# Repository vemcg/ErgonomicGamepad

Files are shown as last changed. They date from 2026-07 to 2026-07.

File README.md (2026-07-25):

# ErgonomicGamepad

Custom ergonomic gaming keypad PCB project (KiCad) with a 4x6 key matrix, hot-swap sockets, and USB-C.

## Overview

This repo contains the schematic, PCB, and production support files for an ATmega32U4-based ergonomic keypad.

## Hardware Summary

| Item | Value |
|---|---|
| MCU | ATmega32U4 (TQFP-44) |
| Key Matrix | 4 rows x 6 columns (24 keys) |
| Switch Interface | MX-compatible Kailh hot-swap sockets |
| USB | USB-C receptacle |
| Clock | 16 MHz crystal |
| Passive Size | 0603 resistors/capacitors |
| Protection/Diodes | 1N4148 matrix diodes, 1N5819WS Schottky |

## Core Project Files

- `ErgonomicGamepad.kicad_sch` - Schematic
- `ErgonomicGamepad.kicad_pcb` - PCB layout
- `ErgonomicGamepad.kicad_pro` - KiCad project
- `jlcpcb/production_files/jlc_sourcing_bom_template.csv` - Main sourcing/BOM table
- `jlcpcb/production_files/verify_stock_before_ordering.csv` - Pre-order stock/sourcing risk checklist (MCU lead time, hand-sourced sockets/connectors/switches)
- `jlcpcb/gerber/` - Manufacturing output folder

## Pinout Baseline

### Matrix

| Signal | Pins |
|---|---|
| ROW1-ROW4 | PF7, PF6, PF5, PF4 |
| COL1-COL6 | PD1, PD2, PD3, PD4, PD5, PD6 |

### Programming Header (ISP)

| Signal | Pin Mapping |
|---|---|
| SCK | PB1 |
| MOSI | PB2 |
| MISO | PB3 |
| RESET | J5 pin 5 -> U1 ~RESET |

## USB-C Implementation (Resolved)

J1 is an HRO `TYPE-C-31-M-12` receptacle - hybrid retention (SMT signal/power
pins plus through-hole shell tabs) for stronger cable-insertion durability
than an SMT-only part. This is a USB 2.0 device-only implementation (power +
D+/D-); no SuperSpeed/Alt-Mode pins are used.

- **Orientation**: fully reversible. Both D+ pads (A6 and B6) are tied
  together at the connector, and both D- pads (A7 and B7) are tied together,
  so the plug works in either orientation.
- **Signal path**: connector D+/D- -> U2 (`USBLC6-2SC6` ESD protection array)
  -> series resistors R1/R2 (20R) -> U1 D-/D+ pins, with TP3/TP4 tapping the
  MCU-side D-/D+ nets for debug access.
- **CC (device-mode/UFP)**: CC1 and CC2 each pull down to GND through a 5.1k
  resistor (R4, R5) - the standard passive UFP presentation, no CC logic IC.
- **Shield/GND**: J1's shield pin (`SH`) ties directly to GND (no RC/ferrite
  isolation).
- **Power path**: VBUS feeds +5V through D1 (`1N5819WS` Schottky) gated by
  JP1 (power-path select jumper - see Jumper Shunts below); J7 (external
  2-pin power connector) feeds +5V directly. The Schottky prevents VBUS from
  being back-fed if J7 external power is connected while a USB cable is also
  plugged in.

## Debug / Test Points

- **TP1-TP7**: internal signal debug points (power-select node, GND
  reference, USB D+/D-, crystal XTAL1/XTAL2, USB regulator cap node) using
  the small `TestPoint_Pad_D1.5mm` footprint - sized for a fine meter probe
  or hook, not a full-size clip.
- **TP8 (+5V) / TP9 (GND)**: dedicated power-rail clip points, intended to
  be placed at the board edge for easy alligator-clip access during bring-up
  and testing. These use the larger `TestPoint_THTPad_D3.0mm_Drill1.5mm`
  footprint (a real drilled through-hole pad, not just a flat SMD pad) so an
  actual clip has something to bite onto. Kept separate from TP2 (which
  stays with the internal signal-debug cluster near the MCU) since GND is a
  single net and a second access point elsewhere costs nothing electrically.

## Footprint Baseline (Current)

- SW1-SW24: `Switch_Keyboard_Hotswap_Kailh:SW_Hotswap_Kailh_MX_Plated_1.00u`
- J1: `Connector_USB:USB_C_Receptacle_HRO_TYPE-C-31-M-12`
- R1-R7: `Resistor_SMD:R_0603_1608Metric`
- C1-C5: `Capacitor_SMD:C_0603_1608Metric`
- D25-D26: `LED_SMD:LED_0603_1608Metric`
- TP1-TP7: `TestPoint:TestPoint_Pad_D1.5mm`
- TP8/TP9: `TestPoint:TestPoint_THTPad_D3.0mm_Drill1.5mm` (edge-mounted power/ground clip points - see Debug / Test Points above)
- J2/J3/J4/J6: `Connector_JST:JST_XH_B5B-XH-A_1x05_P2.50mm_Vertical` (DNP - see Satellite Board Cables below)
- J7: `PinHeader_1x02_P2.54mm_Vertical`
- J5: `PinHeader_2x03_P2.54mm_Vertical`
- JP1/JP2: `Connector_PinHeader_2.54mm:PinHeader_1x02_P2.54mm_Vertical`
- Y1: `Crystal:Crystal_SMD_3215-2Pin_3.2x1.5mm`
- SWR1: `Button_Switch_SMD:SW_SPST_B3U-3000P`

## Jumper Shunts Needed (Not Part of PCBA)

JP1 (power-path select) and JP2 (forces hardware bootloader via U1 pin 33 /
HWB when bridged) are populated as bare 2-pin headers during JLCPCB assembly,
but the assembly process does not install a shunt on them - a jumper shunt is
a friction-fit plastic/metal cap, not a soldered part, so it has to be
installed by hand after the boards arrive.

Buy separately (not on the PCBA BOM):
- **2.54mm 2-pin jumper shunt cap** - e.g. BOOMELE, LCSC `C5305` (~$0.01/unit,
  50-piece minimum order on LCSC). Any standard 2.54mm/0.1" shunt works; this
  is a common commodity part also sold on Amazon/DigiKey/etc.
- Need at least 2 (one per jumper), but buy a small handful (the LCSC MOQ is
  50 anyway) since they're easy to lose.

## Switches & Keycaps Needed (Not Part of PCBA)

SW01-SW24 are Kailh MX hotswap sockets, soldered directly to the board (see
Footprint Baseline above), but the actual keyswitches and keycaps are
separate hand-sourced items that get plugged in after assembly - the whole
point of a hotswap board is that these aren't soldered.

- **Hotswap sockets** (on-board, hand-soldered): Kailh `CPG151101S11-16`,
  LCSC `C5156480` - https://www.lcsc.com/datasheet/C5156480.pdf. Currently
  shows near-zero LCSC stock (consignment-style listing), so plan to
  hand-source and hand-solder these rather than rely on JLCPCB
  auto-placement - see Progress notes below. Need 24 plus a few spares.
  Each socket takes 2 solder joints (through-hole); the extra alignment
  pins in the footprint hold it steady while soldering. For practical
  hobbyist purchasing, the real path is AliExpress - there are multiple
  listings selling genuine Kailh hotswap sockets in small hobbyist-friendly
  quantities (30/90/110-packs), which is how most individual keyboard
  builders actually buy these - or a specialty keyboard-parts retailer
  like splitkb.com, which stocks Kailh hotswap sockets specifically for
  this use case.
- **Keyswitches** (plug into the sockets, not soldered): Cherry MX Brown
  (tactile), official part `MX1A-G1NW`. Also frequently out of stock on
  LCSC - source from a specialty mechanical-keyboard parts retailer instead
  (e.g. KBDfans, NovelKeys, Mechanicalkeyboards.com, or similar). Since the
  socket is switch-agnostic (any standard MX-footprint switch fits), a
  well-regarded MX-compatible clone switch would also work if genuine
  Cherry isn't available. Need 24 plus a few spares.
- **Keycaps**: MX-compatible (cross-stem) keycaps, not yet specced -
  profile (OEM/Cherry/DSA/etc.), material, and colorway are a personal
  choice. Note this layout is a non-standard ergonomic 4x6 matrix, not a
  regular keyboard row layout, so a generic pre-made keycap set is unlikely
  to have correctly-sculpted keycaps for every position - uniform-profile
  (same shape regardless of position) or blank keycaps are the simplest
  option unless a custom set is planned.

## Satellite Board Cables Needed (Not Part of PCBA)

J2/J3/J4/J6 connect the two satellite switch boards to the main board (ROW1-4
+ COL1 per connector - no power needed, see Pinout Baseline). They're marked
DNP on the JLCPCB assembly BOM since through-hole headers get hand-soldered
after the boards arrive, same reasoning as the hotswap sockets above.

- **Male headers** (on-board, hand-soldered): JST-XH 5-pin, `B5B-XH-A`
  (matches the footprint above). Genuine JST stock from **Digi-Key** or
  **Mouser** (search `B5B-XH-A` directly), or cheaper from **LCSC/JLCPCB**
  (search "XH 5P" or the part number `B5B-XH-A(LF)(SN)`) - the latter is also
  orderable through JLCPCB assembly if DNP is ever lifted. Generic
  multi-packs from Amazon/AliExpress work fine too for prototyping. Need 4
  (one per connector) plus spares.
- **Female-to-female cables**: JST-XH 5-pin, both ends female, connecting
  each main-board header to its matching satellite-board header. Target
  length ~3-4in. Best sourced from **AliExpress** (search "JST XH 2.54 5 pin
  cable" - widely available in 10/15/20/30cm, some sellers offer custom
  lengths) or **Amazon** (search "JST XH 5 pin cable" - mostly RC/battery
  sellers, lengths cluster around 15-30cm with some 10cm/~4in options). If
  the exact length/pinout combo isn't available premade, a JST-XH crimp tool
  (~$15-20) plus loose housings/terminals (pennies each, same vendors) makes
  it easy to build the 2 needed cables to spec. Individual wires are
  flexible (stranded, not ribbon) so routing/twisting around the enclosure
  isn't a concern.

## Progress (Brief)

Done:
- Schematic is component-complete.
- Footprints assigned for all currently tracked parts.
- Schematic and PCB baseline are synced.
- ISP signal mapping corrected and documented.
- JLC sourcing workflow files are in place.
- USB-C orientation, CC, ESD, shield, and power-path decisions locked and documented.

Not done yet:
- Component placement refinement.
- PCB routing completion.
- Panelization/mechanical finalization.
- Final DRC-clean release candidate.
- Gerber/BOM/CPL release package for fabrication.
- Firmware development.

## Process Checklist

For the full detailed build, verification, and manufacturing checklist, use [PROCESS.md](PROCESS.md).

---

Last Updated: July 2026
Project Status: Pre-Layout Baseline

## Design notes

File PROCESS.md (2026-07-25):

# ErgonomicGamepad Process Checklist (Detailed)

Use this file as the full grind checklist from project prep through fabrication handoff.

## How To Use This Checklist

1. Work from top to bottom.
2. Check items as you complete them.
3. If blocked, add a short note under the blocked item and continue with the next independent item.
4. Commit often.

## 0) Project Setup (One-Time)

- [X] Install KiCad 10.0+.
- [X] Open `ErgonomicGamepad.kicad_pro`.
- [X] Confirm project opens cleanly (no stale lock-file confusion from old sessions).
- [X] Confirm local libraries needed by footprints are available.
- [X] Create a baseline git commit before making major changes.

Verification:
- [X] Open schematic and PCB once each and confirm they load without missing file errors.

## 1) Requirements Freeze (Before Heavy Layout)

- [X] Confirm matrix goal: 4x6 (24 keys).
- [X] Confirm switch/socket strategy (hot-swap MX).
- [X] Confirm USB-C connector part and orientation strategy.
- [X] Confirm power path strategy and required protection parts.
- [ ] Confirm mounting-hole plan and any enclosure constraints.
- [X] Confirm debug/programming connector strategy (ISP).

USB-C connector part + orientation strategy details:
- [X] Pick the exact connector MPN first (mid-mount vs top-mount, horizontal vs vertical, SMT-only vs hybrid with through-hole shell tabs).
- [X] Confirm your use case is USB 2.0 device-only (power + D+/D-), not full USB-C feature set.
- [X] Decide plug orientation behavior:
- [X] Fully reversible: tie A6 to B6 for D+, and A7 to B7 for D- at the connector footprint.
- [X] Confirm CC implementation for device mode (UFP): place 5.1k pull-down resistors from CC1 and CC2 to GND.
- [X] Verify shield/shell connection plan (direct GND or GND through RC/ferrite policy per your EMI goal) and keep it consistent with board grounding strategy.
- [ ] Confirm mechanical robustness: shell-anchor pad dimensions, courtyard/keepout, and cable insertion stress path.
- [ ] Confirm footprint pin numbering and front/back orientation against the datasheet drawing before routing.
- [ ] Confirm nearby ESD protection placement for D+/D- and VBUS (close to connector, short return path to GND).

Verification for USB-C decision:
- [ ] Schematic symbol pins and footprint pins are cross-checked against connector datasheet pin map.
- [X] Chosen orientation strategy is documented in README so future revisions do not accidentally change behavior.

Recommended default for this project (unless a later constraint overrides it):
- [X] Use a USB-C receptacle with hybrid retention (SMT pins + through-hole shell tabs) for stronger cable-insertion durability.
- [X] Implement fully reversible USB 2.0 routing at the connector (A6/B6 joined for D+, A7/B7 joined for D-).
- [X] Use UFP CC pulldowns: 5.1k from CC1 to GND and 5.1k from CC2 to GND.
- [X] Add USB ESD protection array near connector for D+, D-, and VBUS.
- [X] Tie shield/shell to GND through your chosen policy and keep that policy documented consistently in schematic notes.

Final USB-C signoff checklist (release gate):
- [ ] Hard-edge decision locked: USB-C connector (J1) and side reset switch (SWR1) are both placed on north board edge.
- [ ] Panelization decision locked: avoid mouse-bites/V-score stress features near J1 shell tabs and SWR1 body keepout.
- [ ] J1 footprint and connector mechanical drawing are cross-checked (plug overhang, shell tab footprint, insertion clearance).
- [ ] USB 2.0 reversibility confirmed electrically: A6/B6 tied to D+, A7/B7 tied to D-.
- [ ] CC policy confirmed electrically: CC1 -> 5.1k -> GND and CC2 -> 5.1k -> GND.
- [ ] USB data path conditioning confirmed: series resistors on D+ and D- are placed and value-checked.
- [ ] USB ESD array part is added in schematic with explicit MPN/LCSC fields.
- [ ] USB ESD array footprint is placed close to J1 with short traces and short GND return.
- [ ] Shield/shell grounding policy is explicitly selected (direct GND or RC/ferrite policy) and implemented consistently.
- [ ] DRC/ERC re-run after USB/ESD updates with no unresolved manufacturing-blocking issues.

Verification:
- [ ] All above decisions are written in project notes/README.

## 2) Part Selection and Sourcing

- [X] Choose MPN for each symbol.
- [X] Prefer JLC/LCSC in-stock parts for assembled items.
- [X] Fill LCSC + MPN + Manufacturer in `jlcpcb/production_files/jlc_sourcing_bom_template.csv`.
- [X] Track pre-order stock/sourcing risk in `jlcpcb/production_files/verify_stock_before_ordering.csv`.
- [X] Mark DNP and hand-assembly items explicitly.

Verification:
- [X] No critical schematic component is missing a sourcing plan.
- [X] Every JLC-assembled line has a valid LCSC number or documented alternate.

## 3) Footprints and Mechanical Validity

- [ ] Assign footprint for every symbol.
- [ ] Cross-check each footprint against package dimensions in datasheet.
- [ ] Validate orientation for polarity/pin-1 sensitive parts.
- [ ] Confirm switch pitch/spacing and keycap clearance assumptions.
- [ ] Add/confirm mounting holes and keepouts.
- [ ] Add test points for key debug rails if needed.

Verification:
- [ ] No symbol left without footprint.
- [ ] Orientation-sensitive components are visually verified.

## 4) Schematic Electrical Verification (ERC)

- [ ] Run ERC (`Inspect -> Electrical Rules Checker`).
- [ ] Fix all blocking ERC errors.
- [ ] Document intentional warnings so future checks are clear.
- [ ] Review critical nets manually:
- [ ] MCU power and decoupling topology.
- [ ] USB D+ and D- connectivity.
- [ ] Reset and ISP lines.
- [ ] Matrix row/column mapping.

Verification:
- [ ] ERC is clean of blocking issues.
- [ ] Critical net review is complete and documented.

## 5) Schematic -> PCB Sync

- [ ] Run `Tools -> Update PCB from Schematic`.
- [ ] Confirm no missing-footprint errors.
- [ ] Confirm no accidental footprint remaps.
- [ ] Confirm netlist-level changes are expected.

Verification:
- [ ] PCB reflects current schematic exactly.

## 6) PCB Rule Setup Before Placement

- [ ] Define board outline on `Edge.Cuts`.
- [ ] Set clearance/track/via rules to fab-capable values.
- [ ] Define net classes (power, USB, matrix, etc.).
- [ ] Confirm layer stack/thickness target for fabrication.

Verification:
- [ ] Rules are set before routing starts.

## 7) Component Placement

- [ ] Place switch sockets first (mechanical anchor).
- [ ] Place MCU for practical fanout.
- [ ] Place decoupling caps close to MCU power pins.
- [ ] Place USB-C and nearby support/protection parts tightly.
- [ ] Place headers/test points for easy probe/cable access.
- [ ] Confirm mounting/tool clearance.

Verification:
- [ ] Components are placeable/routable without obvious congestion traps.

## 8) Routing

- [ ] Route power rails first.
- [ ] Route USB differential pair with clean geometry and consistent behavior.
- [ ] Route matrix traces with minimal crossover complexity.
- [ ] Add copper zones and refill.
- [ ] Remove weak geometry (needless neck-downs, awkward acute corners).

Verification:
- [ ] No critical net left in ambiguous state.

## 9) PCB Verification (DRC + Visual)

- [ ] Run DRC (`Inspect -> Design Rules Checker`).
- [ ] Fix all fabrication-blocking DRC issues.
- [ ] Confirm unrouted nets are zero before release (unless intentionally documented).
- [ ] Use 3D view for connector/mechanical collision sanity check.
- [ ] Re-run DRC after each major fix set.

Verification:
- [ ] DRC is clean for manufacturing intent.

## 10) Pre-Release Manufacturing Sanity

- [ ] Silkscreen labels are readable and off exposed pads.
- [ ] Polarized component markings are clear.
- [ ] Reference designators are present for assembly/debug.
- [ ] Fiducials/tooling are present if assembly process needs them.
- [ ] Freeze release commit and tag it.

Verification:
- [ ] Board is reviewable by someone else without guesswork.

## 11) Export Gerbers + Drills

In KiCad PCB Editor:

1. `File -> Plot...`
2. Select output format: `Gerber`
3. Plot required layers:
- [ ] F.Cu
- [ ] B.Cu
- [ ] F.SilkS
- [ ] B.SilkS
- [ ] F.Mask
- [ ] B.Mask
- [ ] Edge.Cuts
4. Click `Plot`.
5. Click `Generate Drill Files...`.
6. Generate Excellon drill files (PTH + NPTH as appropriate).
7. Package Gerbers + drills in one zip file.

Verification:
- [ ] Gerber set includes board outline and both mask layers.
- [ ] Drill files are present and non-empty.

## 12) Export Assembly Files (If JLC Assembly)

- [ ] Export BOM CSV.
- [ ] Export CPL/Pick-and-Place file.
- [ ] Ensure BOM refdes matches CPL refdes exactly.
- [ ] Ensure LCSC numbers are present where JLC places parts.
- [ ] Confirm DNP lines are clearly marked.

Verification:
- [ ] BOM/CPL pair imports without obvious mapping issues.

## 13) Upload and Manufacturer Review

- [ ] Upload Gerber zip to JLCPCB.
- [ ] Confirm board preview, dimensions, layer count, drill interpretation.
- [ ] Upload BOM + CPL if ordering assembly.
- [ ] Resolve rotation, offset, and refdes mapping issues.
- [ ] Review substitutions, price, and lead time.

Verification:
- [ ] Quote is valid and manufacturable with acceptable substitutions.

## 14) Final Release Lock

- [ ] Run ERC and DRC one final time on release revision.
- [ ] Confirm no accidental post-check edits.
- [ ] Save final manufacturing outputs under `jlcpcb/gerber/`.
- [ ] Tag release (example: `v0.1-proto1`).

Verification:
- [ ] Repo, outputs, and tag all match the same final revision.

## Daily Progress Loop (When You Feel Stuck)

1. Pick exactly one section above.
2. Complete 1 to 3 checkboxes only.
3. Run the relevant verification items.
4. Commit with a clear message.
5. Stop and continue tomorrow from the next unchecked item.

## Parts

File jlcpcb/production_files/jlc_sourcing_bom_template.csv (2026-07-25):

Quantity | Value | Footprint | References | LCSC | MPN | Manufacturer | Assembly | Notes
1 | ATmega32U4-A | Package_QFP:TQFP-44_10x10mm_P0.8mm | U1 | C44854 | ATMEGA32U4-AU | Microchip | JLC_SMT | Critical long-lead item; confirm live stock before finalizing order
1 | USBLC6-2SC6 | Package_TO_SOT_SMD:SOT-23-6 | U2 | C7519 | USBLC6-2SC6 | STMicroelectronics | JLC_SMT
1 | Crystal | Crystal:Crystal_SMD_3215-2Pin_3.2x1.5mm | Y1 | C13738 | X322516MLB4SI | YXC Crystal Oscillators | JLC_SMT
1 | USB_C_Receptacle_USB2.0_16P | Connector_USB:USB_C_Receptacle_HRO_TYPE-C-31-M-12 | J1 | C165948 | TYPE-C-31-M-12 | Korean Hroparts Elec | JLC_SMT
1 | AVR-ISP-6 | Connector_PinHeader_2.54mm:PinHeader_2x03_P2.54mm_Vertical_SMD | J5 | C32713283 | HX PZ2.54-2x3P TP | hanxia | JLC_SMT
1 | 1824417 | Connector_Phoenix_MC_HighVoltage:PhoenixContact_MCV_1,5_2-G-5.08_1x02_P5.08mm_Vertical | J7 | C5873683 | 1824417 | Phoenix Contact | JLC_SMT
2 | Jumper_2_Open | Connector_PinHeader_2.54mm:PinHeader_1x02_P2.54mm_Vertical | JP1,JP2 | C124375 | B-2100S02P-A110 | Ckmtw | JLC_SMT | Bare header only; JLCPCB does not install a shunt cap - buy separately and hand-install (see README Jumper Shunts section)
1 | 1N5819WS | Diode_SMD:D_SOD-323 | D1 | C191023 | 1N5819WS | Guangdong Hottech | JLC_SMT
24 | 1N4148WS | Diode_SMD:D_SOD-323 | DM01,DM02,DM03,DM04,DM05,DM06,DM07,DM08,DM09,DM10,DM11,DM12,DM13,DM14,DM15,DM16,DM17,DM18,DM19,DM20,DM21,DM22,DM23,DM24 | C917117 | 1N4148WS | JSMSEMI | JLC_SMT
1 | LED Pwr | LED_SMD:LED_0603_1608Metric | LED1 | C19273151 | YLED0603G | YONGYUTAI | JLC_SMT
1 | LED Dbg | LED_SMD:LED_0603_1608Metric | LED2 | C2286 | KT-0603R | Hubei KENTO Elec | JLC_SMT
2 | 22pF | Capacitor_SMD:C_0603_1608Metric | C1,C2 | C519390 | CC0603JRNPO8BN220 | YAGEO | JLC_SMT
1 | 1uF | Capacitor_SMD:C_0603_1608Metric | C3 | C106215 | CC0603KRX5R7BB105 | YAGEO | JLC_SMT
1 | 4.7uF | Capacitor_SMD:C_0603_1608Metric | C4 | C109456 | CC0603KRX5R6BB475 | YAGEO | JLC_SMT
1 | 100nF | Capacitor_SMD:C_0603_1608Metric | C5 | C14663 | CC0603KRX7R9BB104 | YAGEO | JLC_SMT
2 | 20R | Resistor_SMD:R_0603_1608Metric | R1,R2 | C125758 | RC0603FR-0720RL | YAGEO | JLC_SMT
1 | 10K | Resistor_SMD:R_0603_1608Metric | R3 | C98220 | RC0603FR-0710KL | YAGEO | JLC_SMT
2 | 5.1k | Resistor_SMD:R_0603_1608Metric | R4,R5 | C105580 | RC0603FR-075K1L | YAGEO | JLC_SMT
1 | 1k | Resistor_SMD:R_0603_1608Metric | R6 | C22548 | RC0603FR-071KL | YAGEO | JLC_SMT
1 | 330 | Resistor_SMD:R_0603_1608Metric | R7 | C105881 | RC0603FR-07330RL | YAGEO | JLC_SMT
1 | 10k | Resistor_SMD:R_0603_1608Metric | R8 | C98220 | RC0603FR-0710KL | YAGEO | JLC_SMT
1 | B3U-3000P | Button_Switch_SMD:SW_SPST_B3U-3000P | SWR1 | C963349 | B3U-3000P | Omron | JLC_SMT
24 | SW_DIP_x01 | Switch_Keyboard_Hotswap_Kailh:SW_Hotswap_Kailh_MX_Plated_1.00u | SW01,SW02,SW03,SW04,SW05,SW06,SW07,SW08,SW09,SW10,SW11,SW12,SW13,SW14,SW15,SW16,SW17,SW18,SW19,SW20,SW21,SW22,SW23,SW24 | C5156480 | CPG151101S11-16 | Kailh | DNP_HAND_SOLDER | LCSC listing is near-zero/consignment stock - hand-source from AliExpress or splitkb.com and hand-solder after assembly (see README Switches & Keycaps Needed); need 24 plus spares
4 | Conn_01x05 | Connector_JST:JST_XH_B5B-XH-A_1x05_P2.50mm_Vertical | J2,J3,J4,J6 | C157991 | B5B-XH-A(LF)(SN) | JST | DNP_HAND_SOLDER | Hand-solder after boards arrive; order male headers from Digi-Key/Mouser/LCSC and matching female-to-female JST-XH cables separately (see README Satellite Board Cables Needed); need 4 plus spares
7 | TestPoint | TestPoint:TestPoint_Pad_D1.5mm | TP1,TP2,TP3,TP4,TP5,TP6,TP7 |  |  |  | BARE_PCB | No placed component; in_bom=no, excluded from assembly BOM by design

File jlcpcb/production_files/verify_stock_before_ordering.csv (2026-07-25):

Item | References | Qty Needed | Channel | LCSC / MPN | Risk / Note
ATmega32U4-AU MCU | U1 | 1 | JLC assembly | C44854 / ATMEGA32U4-AU | Critical long-lead item - confirm live LCSC stock immediately before submitting the JLC order
Kailh hotswap sockets | SW01-SW24 | 24 + spares | Hand-source (AliExpress or splitkb.com) | C5156480 / CPG151101S11-16 | LCSC listing is near-zero/consignment stock - do not rely on JLC auto-placement; buy from a hobbyist-quantity AliExpress listing or splitkb.com instead
JST-XH 5-pin male headers | J2,J3,J4,J6 | 4 + spares | Hand-source (Digi-Key/Mouser preferred; LCSC/JLCPCB cheaper alt) | C157991 / B5B-XH-A(LF)(SN) | Confirm current stock at chosen supplier before ordering; genuine JST stock via Digi-Key/Mouser is the safer bet, LCSC/JLCPCB is the budget alternative
JST-XH 5-pin female-to-female cables | (satellite board cables, not a schematic symbol) | 2 | Hand-source (AliExpress or Amazon) |  | Confirm the ~3-4in target length is available premade at the chosen listing; if not, budget for a crimp tool + loose housings/terminals instead
Cherry MX Brown keyswitches (or compatible clone) | (plug into SW01-SW24, not a schematic symbol) | 24 + spares | Hand-source (KBDfans/NovelKeys/Mechanicalkeyboards.com) | MX1A-G1NW | Official Cherry part is frequently out of stock on LCSC - source from a specialty mechanical-keyboard retailer; any MX-compatible switch fits the socket if genuine Cherry is unavailable

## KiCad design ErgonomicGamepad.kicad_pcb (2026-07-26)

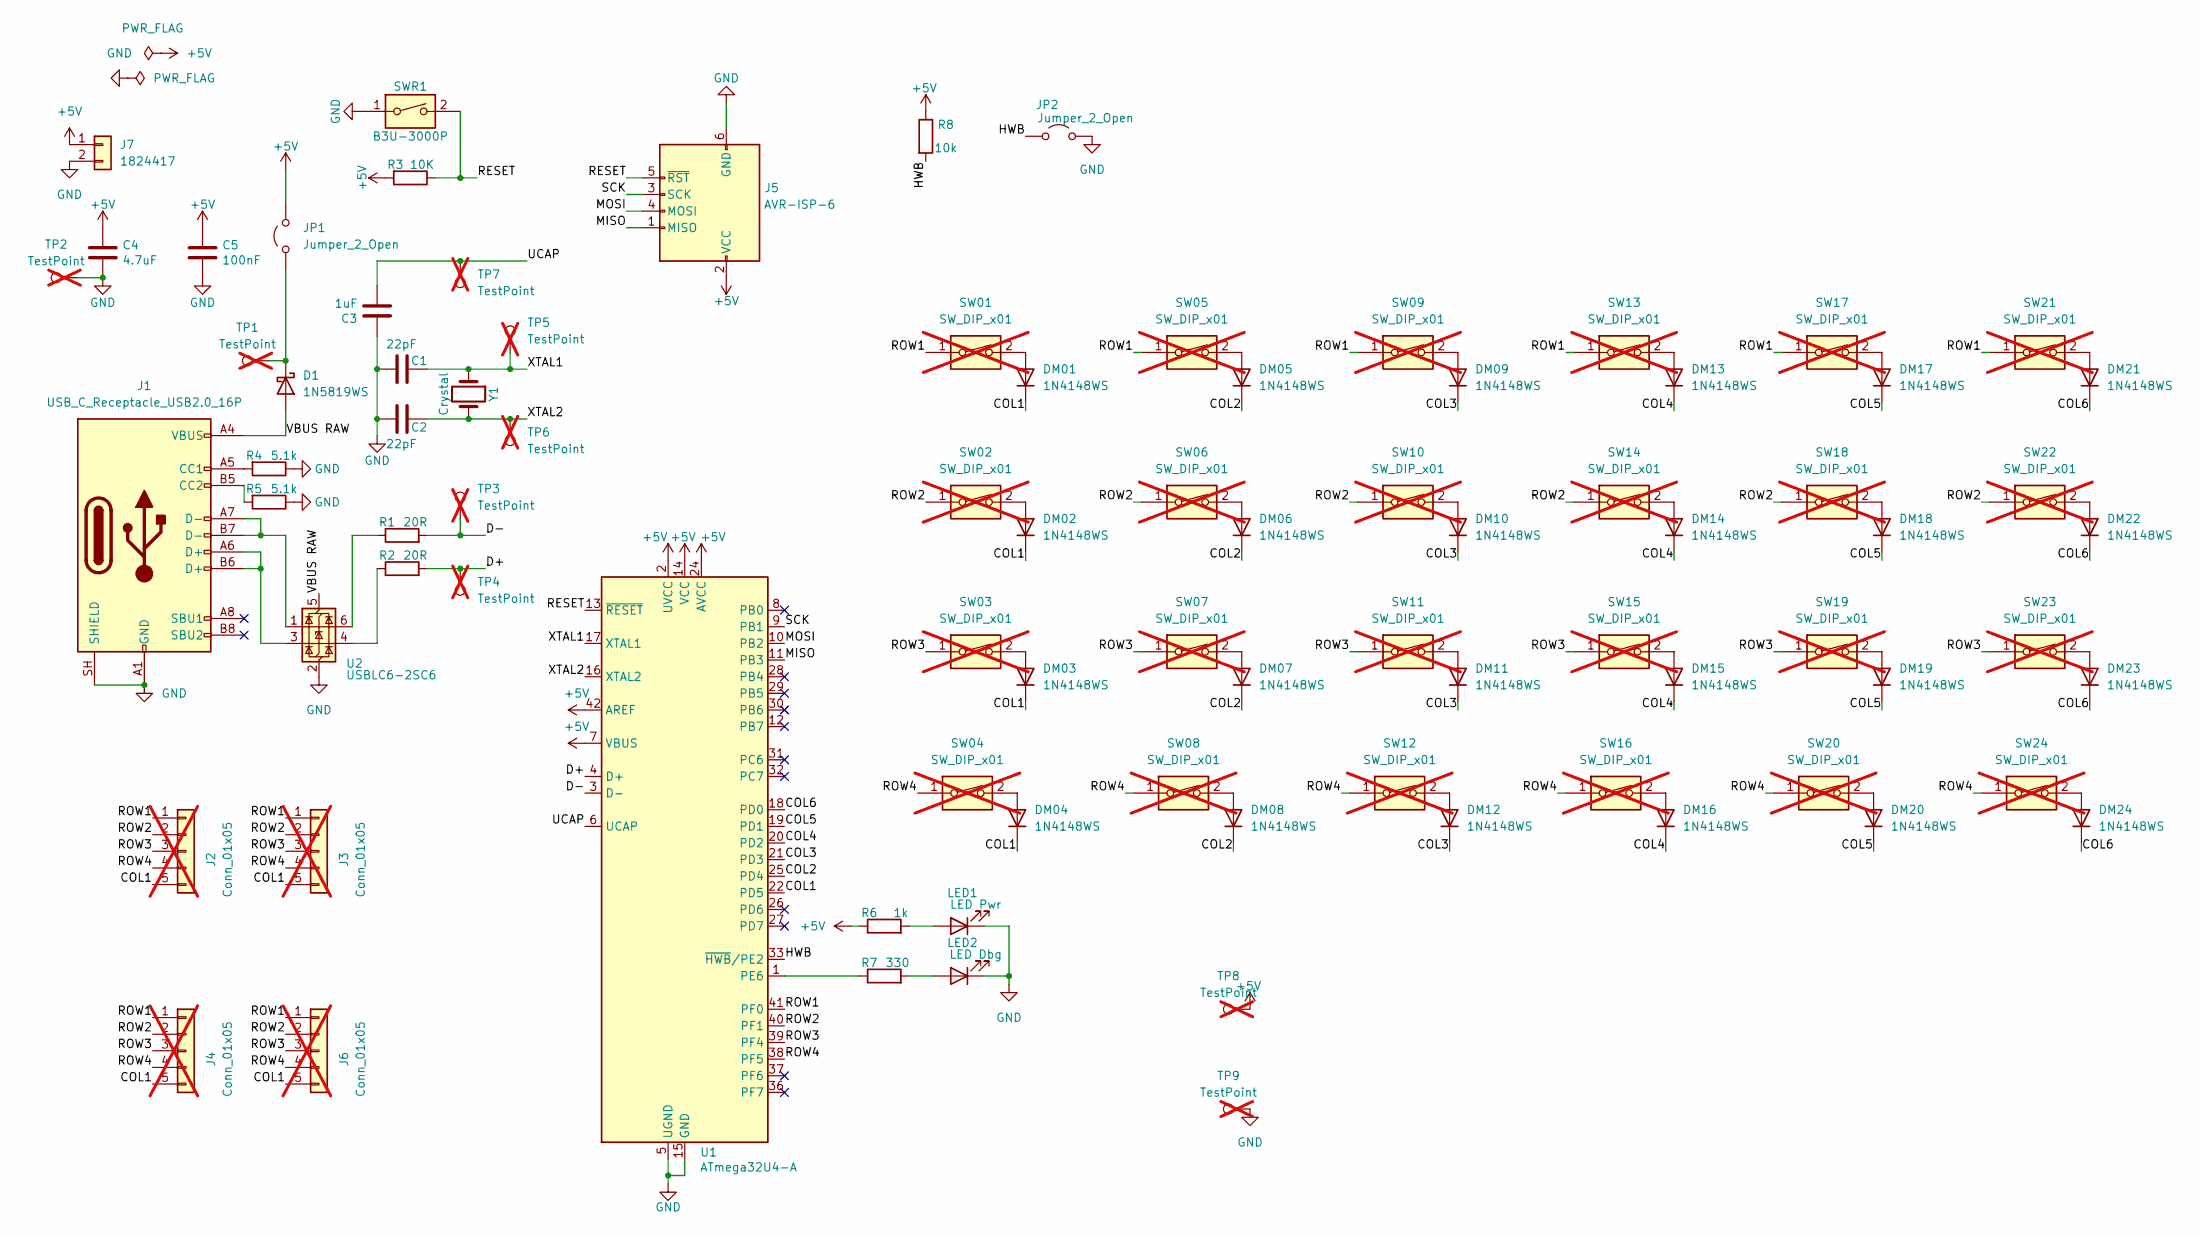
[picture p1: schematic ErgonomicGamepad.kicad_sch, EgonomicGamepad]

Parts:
C1, C2: 22pF; C_0603_1608Metric; MPN CC0603JRNPO8BN220; LCSC C519390
C3: 1uF; C_0603_1608Metric; MPN CC0603KRX5R7BB105; LCSC C106215
C4: 4.7uF; C_0603_1608Metric; MPN CC0603KRX5R6BB475; LCSC C109456
C5: 100nF; C_0603_1608Metric; MPN CC0603KRX7R9BB104; LCSC C14663
D1: 1N5819WS; D_SOD-323; MPN 1N5819WS; LCSC C191023
DM01, DM02, DM03, DM04, DM05, DM06, DM07, DM08, DM09, DM10, DM11, DM12, DM13, DM14, DM15, DM16, DM17, DM18, DM19, DM20, DM21, DM22, DM23, DM24: 1N4148WS; D_SOD-323; MPN 1N4148WS; LCSC C917117
J1: USB_C_Receptacle_USB2.0_16P; USB_C_Receptacle_HRO_TYPE-C-31-M-12; MPN TYPE-C-31-M-12; LCSC C165948
J2, J3, J4, J6: Conn_01x05; JST_XH_B5B-XH-A_1x05_P2.50mm_Vertical; MPN B5B-XH-A(LF)(SN); LCSC C157991; not fitted
J5: AVR-ISP-6; PinHeader_2x03_P2.54mm_Vertical_SMD; MPN HX PZ2.54-2x3P TP; LCSC C32713283
J7: 1824417; PhoenixContact_MCV_1,5_2-G-5.08_1x02_P5.08mm_Vertical; MPN 1824417; LCSC C5873683
JP1, JP2: Jumper_2_Open; PinHeader_1x02_P2.54mm_Vertical; MPN B-2100S02P-A110; LCSC C124375
LED1: LED Pwr; LED_0603_1608Metric; MPN YLED0603G; LCSC C19273151
LED2: LED Dbg; LED_0603_1608Metric; MPN KT-0603R; LCSC C2286
R1, R2: 20R; R_0603_1608Metric; MPN RC0603FR-0720RL; LCSC C125758
R3: 10K; R_0603_1608Metric; MPN RC0603FR-0710KL; LCSC C98220
R4, R5: 5.1k; R_0603_1608Metric; MPN RC0603FR-075K1L; LCSC C105580
R6: 1k; R_0603_1608Metric; MPN RC0603FR-071KL; LCSC C22548
R7: 330; R_0603_1608Metric; MPN RC0603FR-07330RL; LCSC C105881
R8: 10k; R_0603_1608Metric; MPN RC0603FR-0710KL; LCSC C98220
SW01, SW02, SW03, SW04, SW05, SW06, SW07, SW08, SW09, SW10, SW11, SW12, SW13, SW14, SW15, SW16, SW17, SW18, SW19, SW20, SW21, SW22, SW23, SW24: SW_DIP_x01; SW_Hotswap_Kailh_MX_Plated_1.00u; MPN CPG151101S11-16; LCSC C5156480; not fitted
SWR1: B3U-3000P; SW_SPST_B3U-3000P; MPN B3U-3000P; LCSC C963349
TP1, TP2, TP3, TP4, TP5, TP6, TP7: TestPoint; TestPoint_Pad_D1.5mm; not fitted
TP8, TP9: TestPoint; TestPoint_THTPad_D3.0mm_Drill1.5mm; not fitted
U1: ATmega32U4-A; TQFP-44_10x10mm_P0.8mm; MPN ATMEGA32U4-AU; LCSC C44854
U2: USBLC6-2SC6; SOT-23-6; MPN USBLC6-2SC6; LCSC C7519
Y1: Crystal; Crystal_SMD_3215-2Pin_3.2x1.5mm; MPN X322516MLB4SI; LCSC C13738

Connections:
+5V: C4.1, C5.1, J5.2 (VCC), J7.1, JP1.2 (B), R3.2, R6.1, R8.1, TP8.1 (1_1), U1.2 (UVCC), U1.7 (VBUS), U1.14 (VCC), U1.24 (AVCC), U1.34 (VCC), U1.42 (AREF), U1.44 (AVCC)
/COL1: DM01.1 (K), DM02.1 (K), DM03.1 (K), DM04.1 (K), J2.5, J3.5, J4.5, J6.5, U1.22 (PD5)
/COL2: DM05.1 (K), DM06.1 (K), DM07.1 (K), DM08.1 (K), U1.25 (PD4)
/COL3: DM09.1 (K), DM10.1 (K), DM11.1 (K), DM12.1 (K), U1.21 (PD3)
/COL4: DM13.1 (K), DM14.1 (K), DM15.1 (K), DM16.1 (K), U1.20 (PD2)
/COL5: DM17.1 (K), DM18.1 (K), DM19.1 (K), DM20.1 (K), U1.19 (PD1)
/COL6: DM21.1 (K), DM22.1 (K), DM23.1 (K), DM24.1 (K), U1.18 (PD0)
/D+: R2.2, TP4.1 (1_1), U1.4 (D+)
/D-: R1.2, TP3.1 (1_1), U1.3 (D-)
/HWB: JP2.1 (A), R8.2, U1.33 (~HWB/PE2)
/MISO: J5.1 (MISO), U1.11 (PB3)
/MOSI: J5.4 (MOSI), U1.10 (PB2)
/RESET: J5.5 (~RST), R3.1, SWR1.2, U1.13 (~RESET)
/ROW1: J2.1, J3.1, J4.1, J6.1, SW01.1, SW05.1, SW09.1, SW13.1, SW17.1, SW21.1, U1.41 (PF0)
/ROW2: J2.2, J3.2, J4.2, J6.2, SW02.1, SW06.1, SW10.1, SW14.1, SW18.1, SW22.1, U1.40 (PF1)
/ROW3: J2.3, J3.3, J4.3, J6.3, SW03.1, SW07.1, SW11.1, SW15.1, SW19.1, SW23.1, U1.39 (PF4)
/ROW4: J2.4, J3.4, J4.4, J6.4, SW04.1, SW08.1, SW12.1, SW16.1, SW20.1, SW24.1, U1.38 (PF5)
/SCK: J5.3 (SCK), U1.9 (PB1)
/UCAP: C3.2, TP7.1 (1_1), U1.6 (UCAP)
/VBUS RAW: D1.2 (A), J1.A4 (VBUS), J1.A9 (VBUS), J1.B4 (VBUS), J1.B9 (VBUS), U2.5 (VBUS)
/XTAL1: C1.1, TP5.1 (1_1), U1.17 (XTAL1), Y1.1
/XTAL2: C2.1, TP6.1 (1_1), U1.16 (XTAL2), Y1.2
GND: C1.2, C2.2, C3.1, C4.2, C5.2, J1.A1 (GND), J1.A12 (GND), J1.B1 (GND), J1.B12 (GND), J1.SH (SHIELD), J5.6 (GND), J7.2, JP2.2 (B), LED1.1 (K), LED2.1 (K), R4.1, R5.1, SWR1.1, TP2.1 (1_1), TP9.1 (1_1), U1.5 (UGND), U1.15 (GND), U1.23 (GND), U1.35 (GND), U1.43 (GND), U2.2 (GND)
unnamed: D1.1 (K), JP1.1 (A), TP1.1 (1_1)
unnamed: DM01.2 (A), SW01.2
unnamed: DM02.2 (A), SW02.2
unnamed: DM03.2 (A), SW03.2
unnamed: DM04.2 (A), SW04.2
unnamed: DM05.2 (A), SW05.2
unnamed: DM06.2 (A), SW06.2
unnamed: DM07.2 (A), SW07.2
unnamed: DM08.2 (A), SW08.2
unnamed: DM09.2 (A), SW09.2
unnamed: DM10.2 (A), SW10.2
unnamed: DM11.2 (A), SW11.2
unnamed: DM12.2 (A), SW12.2
unnamed: DM13.2 (A), SW13.2
unnamed: DM14.2 (A), SW14.2
unnamed: DM15.2 (A), SW15.2
unnamed: DM16.2 (A), SW16.2
unnamed: DM17.2 (A), SW17.2
unnamed: DM18.2 (A), SW18.2
unnamed: DM19.2 (A), SW19.2
unnamed: DM20.2 (A), SW20.2
unnamed: DM21.2 (A), SW21.2
unnamed: DM22.2 (A), SW22.2
unnamed: DM23.2 (A), SW23.2
unnamed: DM24.2 (A), SW24.2
unnamed: J1.A5 (CC1), R4.2
unnamed: J1.B5 (CC2), R5.2
unnamed: J1.A6 (D+), J1.B6 (D+), U2.3 (I/O2)
unnamed: J1.A7 (D-), J1.B7 (D-), U2.1 (I/O1)
unnamed: LED1.2 (A), R6.2
unnamed: LED2.2 (A), R7.2
unnamed: R1.1, U2.6 (I/O1)
unnamed: R2.1, U2.4 (I/O2)
unnamed: R7.1, U1.1 (PE6)

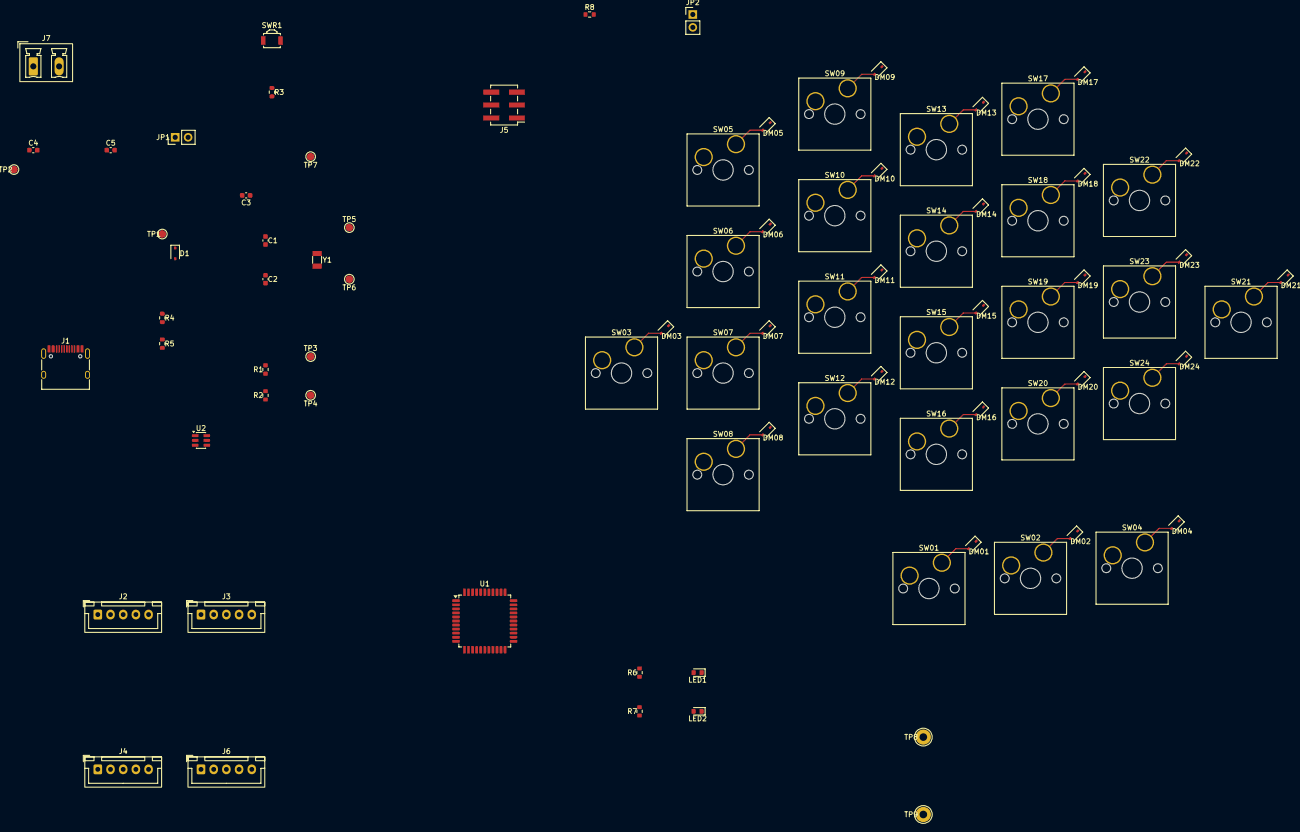
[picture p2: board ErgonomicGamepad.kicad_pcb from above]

Board: 2 copper layers, 86 parts (0 on the bottom side), 57 nets.

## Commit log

2026-06-16 Add KiCad project scaffolding
    Initialize the project container for ErgonomicGamepad with the KiCad project file, PCB placeholder, project settings, and local ignore rules for history, backups, lock files, and caches.
    This keeps the repository baseline separate from the schematic content.
    [ErgonomicGamepad.kicad_pcb]
2026-06-16 Add ErgonomicGamepad schematic
    Add the live schematic for the ergonomic gamepad design, including the verified USB-C power path, ATmega32U4 controller, matrix diodes, connectors, and footprint assignments.
    This commit captures the circuit definition separately from the project scaffolding so future schematic edits are easy to review.
    [ErgonomicGamepad.kicad_sch]
2026-06-25 Update symbols to KiCad 10 library versions
2026-07-04 Assign footprints, fix RESET wiring, select JLCPCB as vendor
    - Selected JLCPCB (+ LCSC parts catalog) as fabrication/assembly vendor
    - Assigned footprints to 82 of 83 components (all but SWR1 reset
    switch, pending real pad dimensions from its datasheet): hotswap
    Kailh sockets for SW1-24 via the kiswitch library, HRO USB-C
    receptacle for J1, and stock KiCad footprints for the remaining
    resistors, caps, LEDs, test points, headers, jumper, and crystal
    - Fixed RESET net: SWR1, J5 pin 5, and U1 pin 13 were previously
    disconnected/mislabeled (RESET and MOSI swapped on the ISP header,
    U1's reset pin floating); now correctly tied together
    - Corrected README status claims that didn't matc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
    [ErgonomicGamepad.kicad_pcb, ErgonomicGamepad.kicad_sch]
2026-07-06 Move ROW1-4 matrix pins from Port B to Port F, fix ISP RESET/MOSI swap
    J5 pin 4 (physical MOSI) was wired to the RESET net while pin 5
    (physical RST) was left no_connect; swapped so RST carries reset
    and MOSI is properly no_connect until the SPI pins are wired.
    ROW1-4 moved off PB6/PB5/PB4/PB3 onto PF0/PF1/PF4/PF5, freeing
    PB1-PB6 for the planned ISP SCK/MOSI/MISO wiring. Removed the
    stale SCK/MISO labels that were left on PF5/PF7 from the old
    matrix layout. COL1-6 remain on PD1-PD6, unchanged.
    Also adds a verification checklist to the README for re-running
    ERC/DRC after pin remaps.
    [ErgonomicGamepad.kicad_sch]
2026-07-06 schematic: map COL1-6 to PD and ROW1-4 to PF
    [ErgonomicGamepad.kicad_sch]
2026-07-06 schematic: set J5 pin 5 to RESET and pin 4 to MOSI
    [ErgonomicGamepad.kicad_sch]
2026-07-06 chore: tech debt cleanup for crystal and reset switch footprints
    [ErgonomicGamepad.kicad_sch]
2026-07-06 chore: pre-layout baseline (no errors, no warnings, no tech debt)
    [ErgonomicGamepad.kicad_pcb]
2026-07-08 Add JLC sourcing BOM tracking files
    [jlc_sourcing_bom_template.csv, jlc_stock_check_queue.csv]
2026-07-08 Snapshot current project state before JLC BOM edits
    [ErgonomicGamepad.kicad_pcb, ErgonomicGamepad.kicad_sch]
2026-07-19 chore: schematic runs ERC clean; parts need specification
    Snapshot pin-remapping work plus JLC BOM tracking updates. Schematic
    passes ERC with no errors, but most placed components still need
    Manufacturer/MPN/Supplier/LCSC fields filled in (see
    UnresolvedPartsPunchList.md for the full punch list).
    [ErgonomicGamepad.kicad_pcb, M1.kicad_sch, Original ErgonomicGamepad.kicad_sch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]
2026-07-19 docs: switch unresolved-parts punch list to HTML only
    Drop the Markdown copy in favor of a single print-ready HTML version.
2026-07-19 schematic: rename matrix diodes to DM## and specify JSMSEMI 1N4148WS
    Rename the 24 switch-matrix diodes from the D2-D24 series to DM01-DM24
    so they're clearly distinguished from D1 (1N5819WS Schottky) and the
    LED indicators (D25/D26). Backfill Manufacturer, MPN, Supplier, and
    LCSC for all 24 with JSMSEMI 1N4148WS (LCSC C917117), replacing the
    dead Vishay datasheet link with LCSC's hosted copy. Also fills in
    previously-missing Supplier/LCSC properties on three diodes that
    lacked them entirely.
    [ErgonomicGamepad.kicad_sch]
2026-07-19 pcb: update from schematic after matrix diode renumbering
    Sync footprint references (D2-D24 -> DM01-DM24) and part fields on the
    PCB following the schematic-side matrix diode rename and LCSC part
    backfill.
    [ErgonomicGamepad.kicad_pcb]
2026-07-20 schematic+pcb: mark JP1/TP1-TP7 as DNP and not real parts
    JP1 (solder jumper) and TP1-TP7 (test points) are bare PCB pads, not
    sourced components, so mark them Do Not Populate and excluded from
    BOM, and drop the empty Datasheet field (Manufacturer/MPN/Supplier/
    LCSC were never set on these). PCB updated from schematic to match.
    [ErgonomicGamepad.kicad_pcb, ErgonomicGamepad.kicad_sch]
2026-07-20 schematic+pcb: rename D25/D26 to LED1/LED2, specify parts
    Rename the power and debug indicator LEDs to LED1/LED2 for clarity.
    Backfill Manufacturer/MPN/LCSC/Datasheet: LED1 (Pwr, green) with
    YONGYUTAI YLED0603G (LCSC C19273151), LED2 (Dbg, red) with Hubei
    KENTO Elec KT-0603R (LCSC C2286). PCB updated from schematic to match.
    [ErgonomicGamepad.kicad_pcb, ErgonomicGamepad.kicad_sch]
2026-07-20 schematic+pcb: confirm U2 ESD part, add JP2 hardware bootloader jumper
    U2 (USBLC6-2SC6): backfill LCSC C7519 and switch to LCSC-hosted
    datasheet; verified via netlist trace that it's correctly wired to
    the USB-C D+/D-/VBUS lines, confirming it's the right part for this
    circuit.
    JP1: convert from a solder jumper to a real 2-pin header
    (Connector_PinHeader_2.54mm, Ckmtw B-2100S02P-A110 / LCSC C124375)
    so a physical shunt can be inserted/removed by hand; flip it back to
    a populated, in-BOM part.
    JP2 (new): same physical-jumper header, wired to U1 pin 33
    (PE2/HWB) and GND, so bridging it forces the ATmega32U4's hardware
    DFU bootloader on reset. R8 (new, 10k) pulls PE2/HWB up to +5V so
    the pin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
    [ErgonomicGamepad.kicad_pcb, ErgonomicGamepad.kicad_sch]
2026-07-20 schematic+pcb: specify U1 (ATmega32U4-AU) part data
    Backfill Manufacturer (Microchip), MPN (ATMEGA32U4-AU), and LCSC
    (C44854), and switch the datasheet link to LCSC's hosted copy.
    Picked the plain -AU variant over -AUR (reel) for better stock
    (1,356 vs 24 units), same TQFP-44 package matching the footprint
    already in use.
    [ErgonomicGamepad.kicad_pcb, ErgonomicGamepad.kicad_sch]
2026-07-20 schematic+pcb: specify J2/J3/J4/J6 headers, match connector pinouts
    Backfill Manufacturer (Ckmtw), MPN (B-2100S08P-A110), LCSC (C124381),
    and datasheet for the J2/J3/J4/J6 edge-connector headers - confirmed
    through-hole (thru_hole pads), matching the existing vertical
    PinHeader footprint.
    Reorient all four connectors to a consistent, matched pin-to-signal
    mapping (ROW1-4 on pins 3-6, COL1 on pin 7 across all of them,
    previously J4/J6 were mirrored relative to J2/J3) so a standard
    straight ribbon cable works without needing a reversed/twisted crimp.
    Verified via netlist export and a clean ERC pass.
    [ErgonomicGamepad.kicad_pcb, ErgonomicGamepad.kicad_sch]
2026-07-20 schematic: specify R1-R8 resistor parts
    Backfill Manufacturer, MPN, LCSC, and datasheet for all eight
    resistors using YAGEO's RC0603FR-07 series throughout for BOM
    consistency, matching the existing 0603 footprint:
    - R1/R2 (20R): RC0603FR-0720RL, LCSC C125758
    - R3/R8 (10k): RC0603FR-0710KL, LCSC C98220
    - R4/R5 (5.1k): RC0603FR-075K1L, LCSC C105580
    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
    [ErgonomicGamepad.kicad_sch]
2026-07-20 schematic: specify C1-C5 capacitor parts
    Backfill Manufacturer, MPN, LCSC, and datasheet for all five
    capacitors using YAGEO parts matching the existing 0603 footprint:
    - C1/C2 (22pF): CC0603JRNPO8BN220, LCSC C519390, NP0/C0G dielectric
    (stable temperature coefficient, appropriate for crystal load caps)
    - C3 (1uF): CC0603KRX5R7BB105, LCSC C106215, X5R
    - C4 (4.7uF): CC0603KRX5R6BB475, LCSC C109456, X5R
    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
    [ErgonomicGamepad.kicad_sch]
2026-07-20 schematic: specify SWR1 as Omron B3U-3000P side-actuated switch
    SWR1 (reset button) needs to be side-mounted at the board edge and
    momentary (not on/off, which would hold RESET low indefinitely).
    Went through two candidates before landing here: TS24CA looked
    right-angle in text listings but its actual mechanical drawing shows
    a top-actuated profile, so it was dropped. Omron B3U-3000P is
    confirmed genuinely side-actuated directly from KiCad's own bundled
    footprint description ("Side-actuated Model"), and KiCad already
    ships a verified footprint for this exact part
    (Button_Switch_SMD:SW_SPST_B3U-3000P), so no custom footprint
    guessing was needed. LCSC C963349.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
    [ErgonomicGamepad.kicad_sch]
2026-07-21 schematic+docs: specify SW01-24 hotswap sockets, mark DNP, document hand-sourcing
    SW01-24 backfilled with Kailh CPG151101S11-16 (LCSC C5156480), the
    closed-ring hotswap socket variant. Set DNP=yes (in_bom stays yes) so
    JLCPCB fabricates the correct pads/holes but skips auto-placement,
    since this part shows near-zero LCSC stock.
    README: documents hand-sourcing for the sockets, the Cherry MX Brown
    switches that plug into them, and keycaps, plus where to actually buy
    the sockets (AliExpress small-quantity listings or splitkb.com) since
    LCSC/JLCPCB isn't a reliable channel for this part category. Also
    fixed a stale footprint reference for SWR1.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
    [ErgonomicGamepad.kicad_sch]
2026-07-24 Replace J2/J3/J4/J6 8-pin headers with 5-pin JST-XH, mark DNP
    Satellite boards only need ROW1-4 + COL1 (matrix scanning needs no
    local power), so drop the unused +5V/GND pin and two spares. Headers
    are hand-soldered post-assembly, not JLCPCB-placed. Document vendor
    sourcing for the JST-XH headers and F-F cables in the README.
    [ErgonomicGamepad.kicad_sch]
2026-07-24 Remove dangling ground symbols on DNP J2/J3/J4/J6 connectors
    Connectors and wiring are now properly specified: unused ROW/COLL
    pins carry no-connect flags to satisfy ERC, and the stray GND
    symbols left over from the JST-XH swap are deleted. PCB footprints
    resynced from schematic to match.
    [ErgonomicGamepad.kicad_pcb, ErgonomicGamepad.kicad_sch]
2026-07-24 Mirror footprint placement from schematic and fill JST connector datasheets
    Add scripts/mirror_schematic_layout.py to copy footprint position/rotation
    from the schematic onto the PCB (respecting locked footprints and nets that
    already have routed copper), plus lock-all/unlock-all helpers for freezing a
    placement pass before adding new parts. Also fill in the Datasheet field for
    J2/J3/J4/J6 (JST XH B5B-XH-A, LCSC C157991).
    [ErgonomicGamepad.kicad_pcb, ErgonomicGamepad.kicad_sch]
2026-07-25 Fill JST connector sourcing fields, refresh production reports, and lock USB-C decisions
    - J2/J3/J4/J6: fill Manufacturer/MPN/Supplier/LCSC (JST B5B-XH-A(LF)(SN), C157991)
    - Regenerate jlc_sourcing_bom_template.csv from current schematic state
    - Rename jlc_stock_check_queue.csv -> verify_stock_before_ordering.csv and
    repurpose it as a pre-order stock/sourcing risk checklist now that all
    parts carry LCSC numbers
    - Remove stale current_sch_fields.csv scratch export
    - Regenerate erc-report.rpt and drc-report.rpt against current schematic/PCB
    - Document resolved USB-C implementation (reversible orientation, CC
    pulldowns, ESD array, shield grounding, power-path gating) in README
    - Update PR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
    [ErgonomicGamepad.kicad_pcb, ErgonomicGamepad.kicad_sch, M1.kicad_sch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]
2026-07-25 Add TP8/TP9 power-rail test points, group keys, and arrange all 24 on a 20mm grid
    - Add TP8 (+5V) / TP9 (GND) edge-mounted clip test points via schematic +
    Update PCB from Schematic, using a 3mm THT pad footprint suited to
    alligator/hook clips (distinct from TP1-7's fine-probe pads); document
    the split in README
    - Establish SW01/DM01 as the validated "key" placement template: diode
    clear of the socket courtyard, correct cathode-to-column orientation,
    connecting trace routed, silkscreen labels matching the rest of the board
    - Add 03_apply_key_template.py to replicate that template's relative
    offset/rotation/trace onto SW02-24/DM02-24, including a fix for pads that
    carry their ow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
    [ErgonomicGamepad.kicad_pcb, ErgonomicGamepad.kicad_sch]
2026-07-26 Add key move/align scripts and begin ergonomic stagger adjustments
    - Add 06_move_key.py: translate a whole key (switch + diode + connecting
    trace) up/down/left/right by a specified distance - a pure translation,
    so no pad-angle fix is needed (unlike 03/05's rotated diode placement)
    - Add 07_align_key.py: move one key to match another's X or Y exactly,
    computing the required delta automatically rather than taking a
    specified distance
    - Relocate Key01/Key02/Key04 (column 1, rows 1/2/4) into their own
    offset row toward the lower-right, and nudge Key17-20/Key21-24 and the
    whole board per iterative ergonomic placement adjustments
    - Regenerate drc-report.rpt against the current placeme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
    [ErgonomicGamepad.kicad_pcb]
